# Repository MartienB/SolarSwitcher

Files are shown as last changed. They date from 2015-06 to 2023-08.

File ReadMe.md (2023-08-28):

# SolarSwitcher

## Goal
The goal of the SolarSwitcher project is to develop a device which can reliably power a USB powered device (in this case a Raspberry PI) from a small solar panel. The uptime of the USB powered device will be garanteed by switching to a secondary power supply in case the battery voltage of the solar panel will drop below a certain level.

## Requirements
- The device should consist mainly of parts I've lying around.
- The device should be durable, so no loose wires and breadboards
- The device should be able to relay its status (show statistics on connected RPI)
- The device should be power efficient
- The device should work if either power supply is disconnected 
- The power to the connected (USB powered) device shouldn't be interuppted while switching power supplies

## Prototype

Build a prototype with breadboards, loose wires and salvaged parts. Capacitor bank is way to big to use in final design.

## Version 1:

Design based around a simple relay board and using micro USB connectors for connecting the input power sources.

## Version 2:

Replaced relay board for a relay, diode and two leds (with resistors). Micro USB connectors were to fragile in the first version so we're now using USB B connectors

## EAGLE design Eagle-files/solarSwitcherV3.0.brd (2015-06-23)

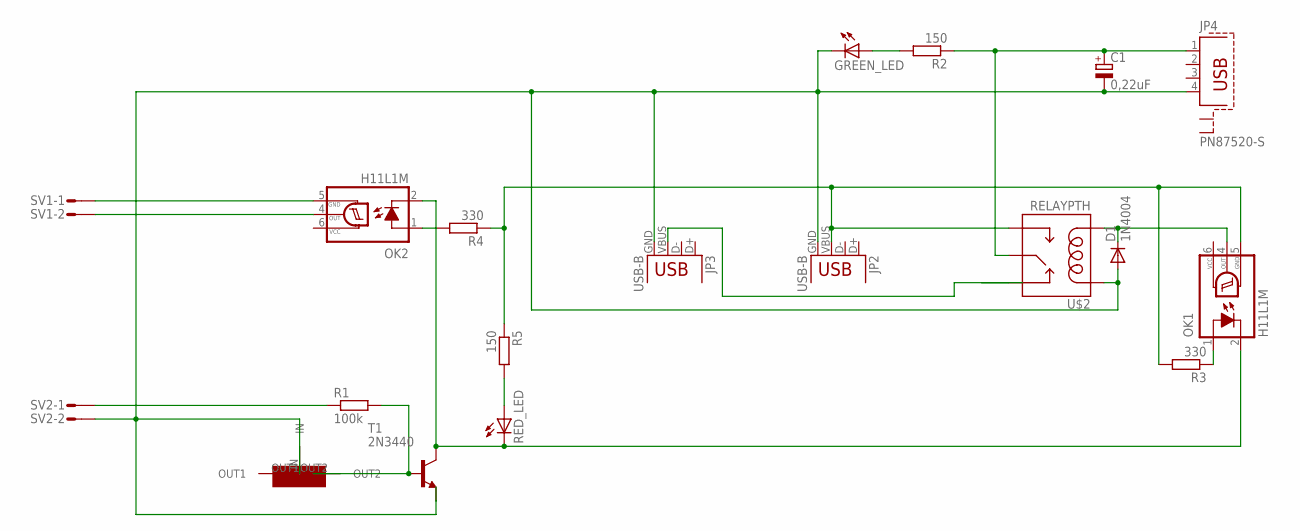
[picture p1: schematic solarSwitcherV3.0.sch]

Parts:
C1: 0,22uF; 150CLZ-1014
D1: 1N4004; DO41-10
GREEN_LED: LED5MM
JP2, JP3: USB-B; USB-B-PTH
JP4: PN87520-S
OK1, OK2: H11L1M; DIL06
R1: 100k; 0207/10
R2, R5: 150; 0207/10
R3, R4: 330; 0207/10
RED_LED: LED5MM
SV1, SV2: L02P
T1: 2N3440; TO5
U$2: RELAYPTH; SRD-05VDC-SL-C
U$5: 20k; POT_TRIMMER

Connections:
unnamed: R1.2, T1.2 (B), U$5.OUT2
unnamed: OK2.1 (A), R4.2
unnamed: OK2.4 (OUT), SV1.2
unnamed: R1.1, SV2.1
unnamed: JP3.VBUS, U$2.SWCLOSED (SWCLOSE)
unnamed: OK2.5 (GND), SV1.1
unnamed: C1.+, JP4.1, R2.1, U$2.SWCOMMON
unnamed: OK1.2 (C), OK2.2 (C), RED_LED.K (C), T1.3 (C)
unnamed: JP2.VBUS, OK1.5 (GND), R3.2, R4.1, R5.1, U$2.SWOPEN
unnamed: GREEN_LED.A, R2.2
unnamed: R5.2, RED_LED.A
unnamed: C1.-, D1.A, GREEN_LED.K (C), JP2.GND, JP3.GND, JP4.4, SV2.2, T1.1 (E), U$2.COIL1, U$5.IN
unnamed: D1.C, OK1.4 (OUT), U$2.COIL0
unnamed: OK1.1 (A), R3.1
VCC: OK1.6 (VCC), OK2.6 (VCC)

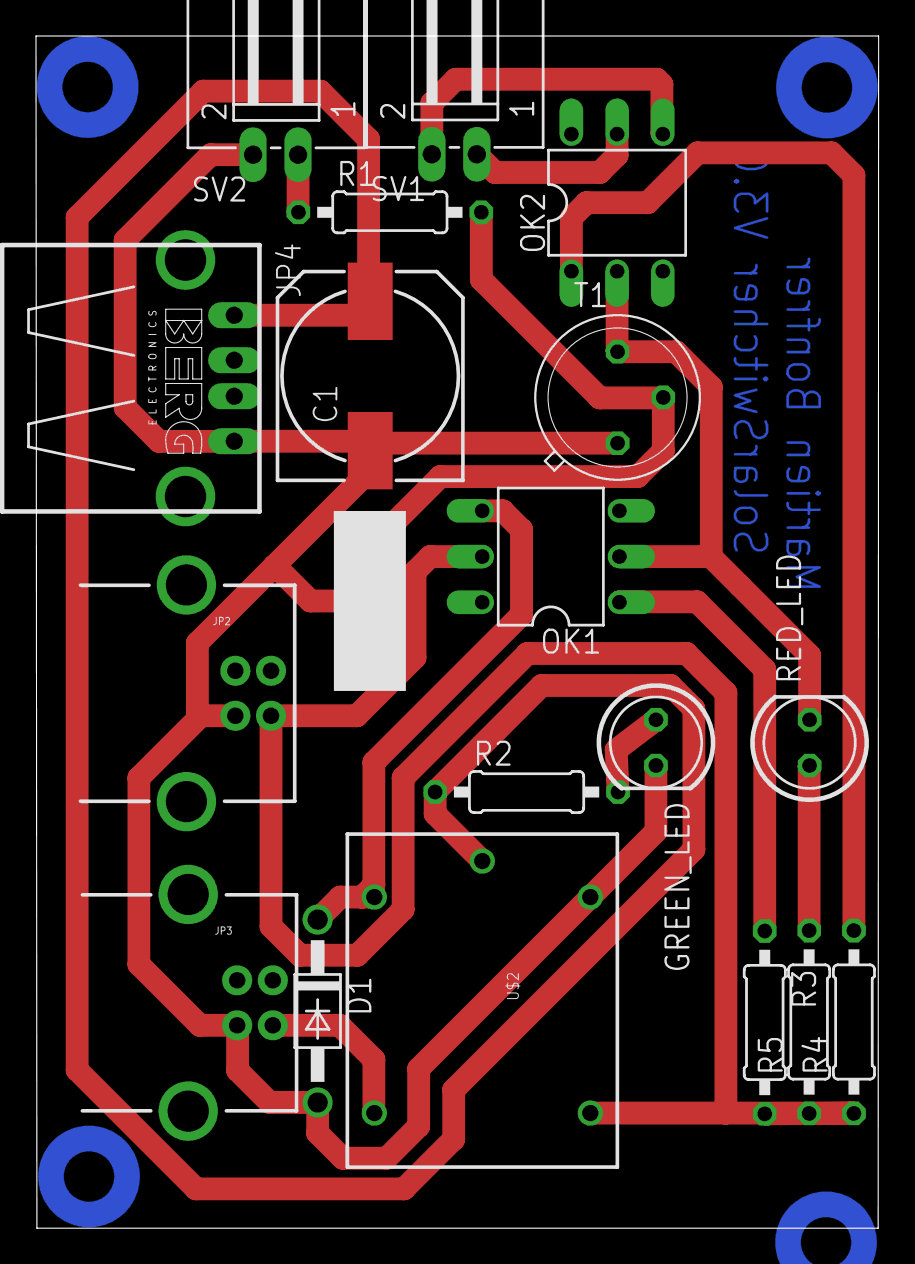
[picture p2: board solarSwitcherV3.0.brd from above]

Board: 2 copper layers, 46.8 x 66.2 mm, 19 parts (0 on the bottom side), 15 nets.

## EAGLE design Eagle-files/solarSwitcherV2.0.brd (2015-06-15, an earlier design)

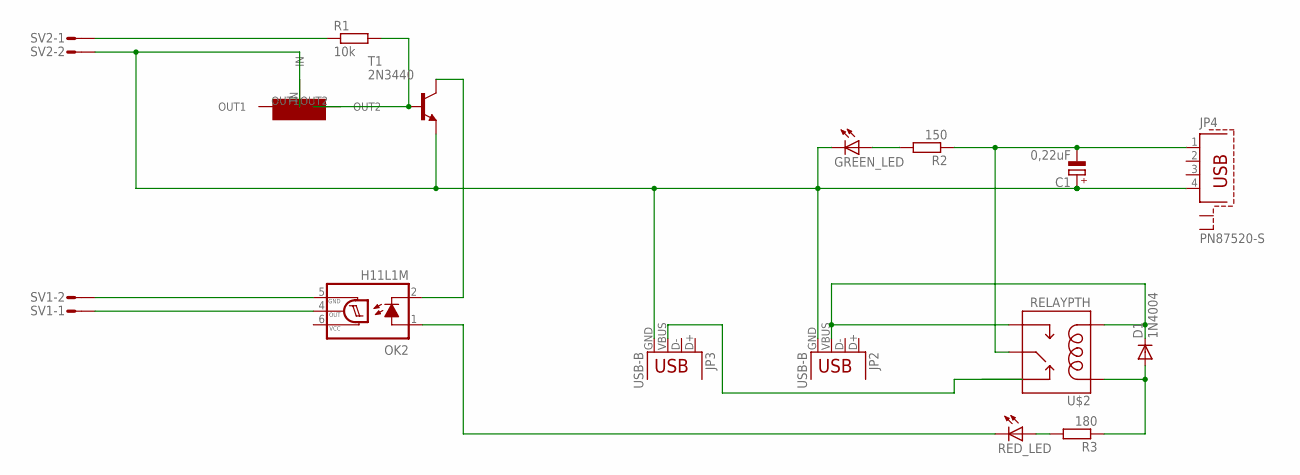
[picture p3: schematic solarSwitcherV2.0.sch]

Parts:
C1: 0,22uF; 150CLZ-1014
D1: 1N4004; DO41-10
GREEN_LED: LED5MM
JP2, JP3: USB-B; USB-B-PTH
JP4: PN87520-S
OK2: H11L1M; DIL06
R1: 10k; 0207/10
R2: 150; 0207/10
R3: 180; 0207/10
RED_LED: LED5MM
SV1, SV2: L02P
T1: 2N3440; TO5
U$2: RELAYPTH; SRD-05VDC-SL-C
U$5: 20k; POT_TRIMMER

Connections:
unnamed: R1.2, T1.2 (B), U$5.OUT2
unnamed: C1.-, JP4.1, R2.1, U$2.SWCOMMON
unnamed: OK2.1 (A), RED_LED.K (C)
unnamed: OK2.4 (OUT), SV1.1
unnamed: R1.1, SV2.1
unnamed: JP3.VBUS, U$2.SWCLOSED (SWCLOSE)
unnamed: OK2.5 (GND), SV1.2
unnamed: C1.+, GREEN_LED.K (C), JP2.GND, JP3.GND, JP4.4, SV2.2, T1.1 (E), U$5.IN
unnamed: OK2.2 (C), T1.3 (C)
unnamed: D1.A, R3.1, U$2.COIL1
unnamed: D1.C, JP2.VBUS, U$2.COIL0, U$2.SWOPEN
unnamed: GREEN_LED.A, R2.2
unnamed: R3.2, RED_LED.A
VCC: OK2.6 (VCC)

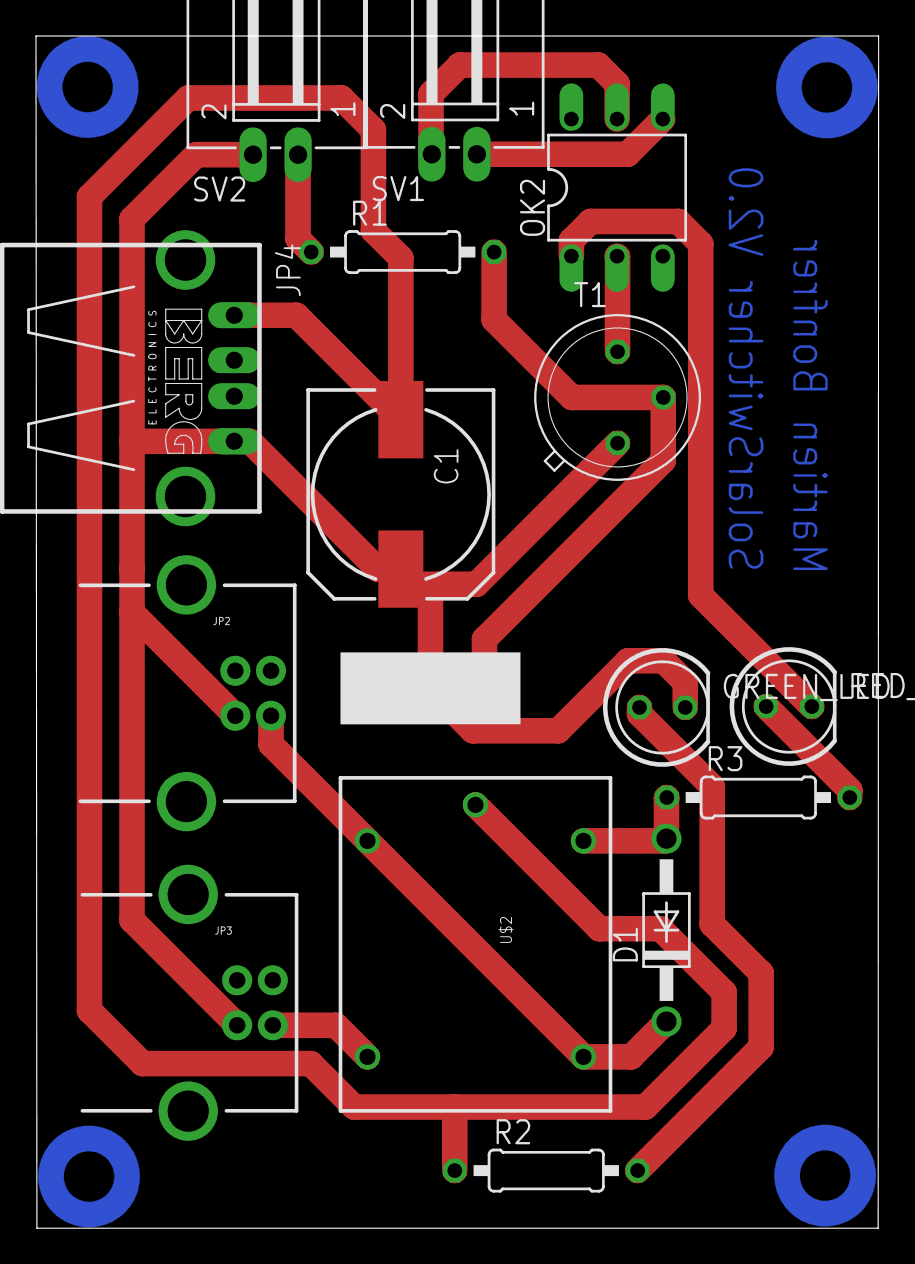
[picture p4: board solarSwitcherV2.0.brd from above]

Board: 2 copper layers, 46.8 x 66.2 mm, 16 parts (0 on the bottom side), 13 nets.

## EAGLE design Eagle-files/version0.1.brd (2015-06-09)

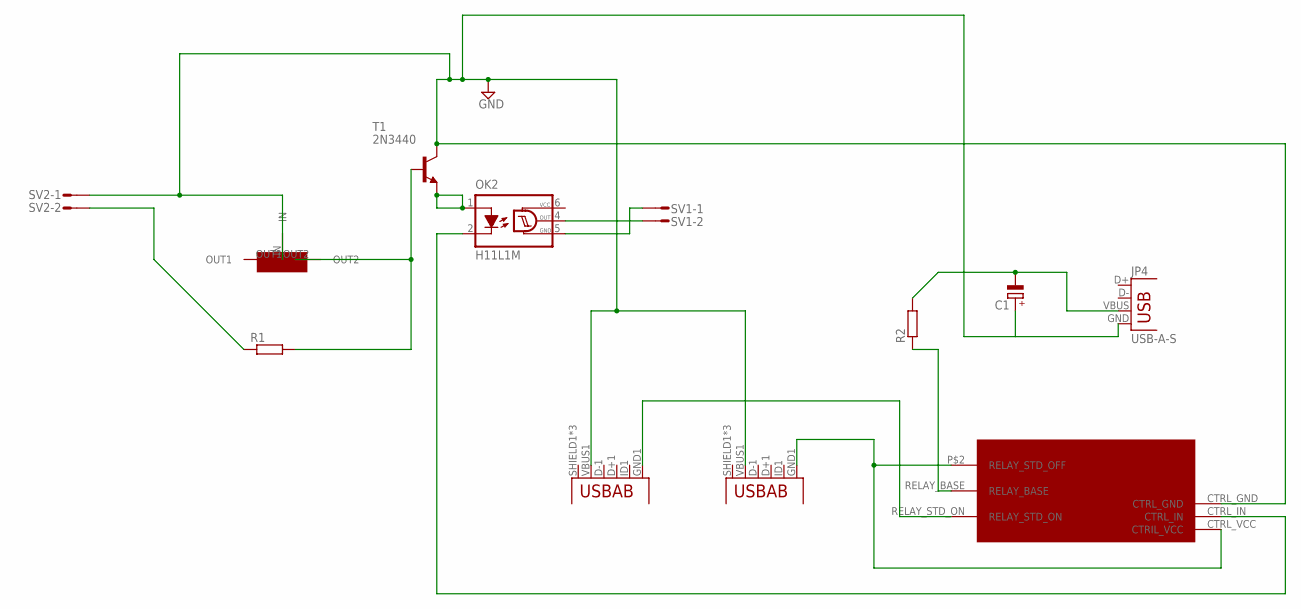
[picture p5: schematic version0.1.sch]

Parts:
C1: CPOL-EU150CLZ-1014; 150CLZ-1014
JP2, JP3: USB-ABCONN-11794; USB-AB-MICRO-SMD_V03
JP4: USB-A-S
OK2: H11L1M; DIL06
R1, R2: R-EU_VMTB60; VMTB60
SV1, SV2: L02P
T1: 2N3440; TO5
U$1: RELAY_BOARD
U$5: POT_TRIMMER

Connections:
GND: C1.+, JP2.VBUS1 (VBUS), JP3.VBUS1 (VBUS), JP4.GND, SV2.1, T1.3 (C), U$1.CTRL_GND, U$5.IN
unnamed: R1.2, T1.2 (B), U$5.OUT2
unnamed: C1.-, JP4.VBUS, R2.2
unnamed: OK2.2 (C), U$1.CTRL_IN
unnamed: JP2.GND1 (GND), U$1.CTRL_VCC (CTRIL_VCC), U$1.P$2 (RELAY_STD_OFF)
unnamed: R1.1, SV2.2
unnamed: JP3.GND1 (GND), U$1.RELAY_STD_ON
unnamed: OK2.5 (GND), SV1.1
unnamed: OK2.1 (A), T1.1 (E)
unnamed: OK2.4 (OUT), SV1.2
unnamed: R2.1, U$1.RELAY_BASE
VCC: OK2.6 (VCC)

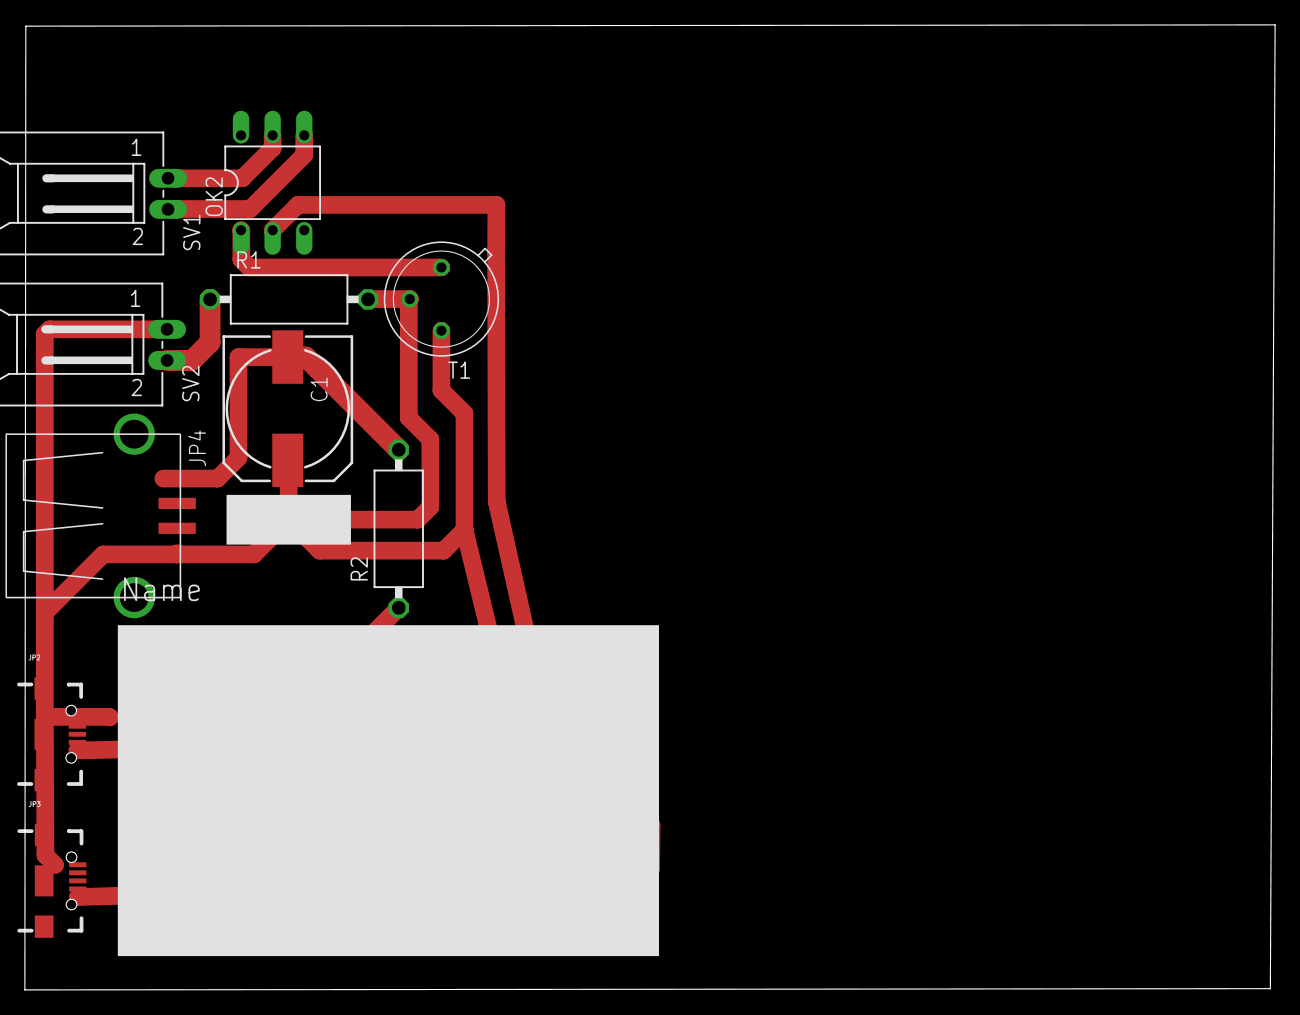
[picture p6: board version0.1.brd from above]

Board: 2 copper layers, 100.5 x 77.6 mm, 12 parts (0 on the bottom side), 11 nets.

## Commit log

2015-06-09 added custom Eagle Lib files
    [version0.1.brd, version0.1.sch]
2015-06-10 Started on redesigning the board for ver. 2.0
    [solarSwitcherV2.0.brd, solarSwitcherV2.0.sch]
2015-06-10 Removed relay-board and replaced with seperate relay and diode
    [solarSwitcherV2.0.brd, solarSwitcherV2.0.sch]
2015-06-12 Added status leds
    [solarSwitcherV2.0.brd, solarSwitcherV2.0.sch]
2015-06-15 Added missing leds
    [solarSwitcherV2.0.brd, solarSwitcherV2.0.sch]
2015-06-22 Started on version 3.0
    [solarSwitcherV3.0.brd, solarSwitcherV3.0.sch]
2015-06-23 Placed and connected all components
    [solarSwitcherV3.0.brd, solarSwitcherV3.0.sch]

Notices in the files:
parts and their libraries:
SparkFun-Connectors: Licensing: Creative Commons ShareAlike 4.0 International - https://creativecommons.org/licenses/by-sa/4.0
